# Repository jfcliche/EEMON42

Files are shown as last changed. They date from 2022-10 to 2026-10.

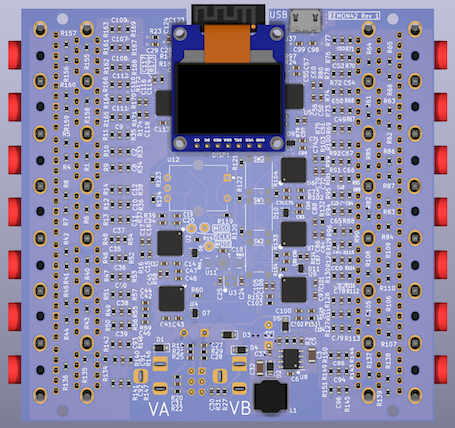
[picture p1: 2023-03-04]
software/sim/eemon42.png

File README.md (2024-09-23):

# EEMON42
ESP32-C3-based 42-channel home energy monitor using the Analog Device ADE7816 emergy monitor chip

Features

  - 42 Current monitoring inputs with 3.5 mm jacks for current transformers
  - Single board, 10x10 cm design with OLED screen with a OLED/switch/rotary encoder user interface
  - Two AC voltage for split phase voltage monitoring and board powering
  - Micropython control software with MQTT telemetry streamed over WiFi

# Status

  V0 Hardware
    - Board is built. 
    - Hardware validation:
      - Switcher works. Board can be powered via USB or AC jacks. 
      - Can operate the ESP32 via the USB and micropython. 
      - All buttons work.
      - OLED display works
      - Only one ADE7816 is populated so far, but we can read registers.
    - Todo: 
      - Check analog inputs of ADE7816. Populate rest of the board. Calibrate all inputs.

  Software
    - Building basic micropyton modules
    - Todo: 
      - Implement main loop and monitoring/GUI tasks as coroutines. Improve display functions. Integrate with Home Assistant.

# Design Details:
- Accurate Energy monitoring performed by seven ADE7816
  - ESP32-C3 controller implemented with a Espressif ESP32-C3-WROOM-02 or AI Thinker ESP-C3-13 module, providing 
      - Single core RISC-V 160 MHz processor
      - 4 MB flash
      - Wifi, Bluetooth
      - Embedded USB controller
  - 96x64 pixel, 0.96" OLED display
  - 3 pushbutton keys 
  - Rotary encoder with integrated push button
  - Dual 9-15VAC inputs for line voltage monitoring and powering the board
  - Micro-USB connector for UART programming and JTAG debugging, and alternate board powering      
  - Integrated DC-DC converter for wide input voltage range

# Rationale

The EEMON42 was developed as personal project for learning all the steps to build an embedded controller project from A to Z, starting from from schematics & layout, online PCB manufacturing, hand soldering of high density SMD devices, an developing the embedded controller software. More specifically, this includes:

   - Learn KiCAD 6.0 and learn to place and route designs
   - Use PCBWay or JLCPCB to manufacture the PCB
   - Learn SMD soldering techniques for sizes down to 0603 and QFN 0.5mm pitch devices
   - Learn the internal architecture of the ESP32-C3-based module
   - Software development tools (Visual Studio Code / Platform IO / ESP IDF/ Micropython etc)

# History

2022/06: Design start
2022/12: Board was manufactured by PCBJLC. Board is assembled. Preliminary hardware verification is performed: power, ESP32, buttons and OLED display works with Micropython. Discovered bug in esptool that prevent the flashing stub to operate when USB-enabled micropython has booted first.
2023/03: ADE7816 is installed. Successful communication with it. Implement Python object for it. Implement SPI object to handle SPI CS pins shared with buttons and pin interrupts.

# Known bugs & gotcha's:

v1 hardware:
  - GPIO9 can be pull down and prevent micropython boot if encoder is left in mid-position
  - Missing GPIO2 & GPIO8 pullup (but still works without those)
  - A reset switch would be nice, but is becoming les and less necessary as hardware matures
  - A power LED would prevent accidental soldering on a powered board...
  - Pad and copper pour cleareaces too small close to USB connector: rookie solderers might cause shorts when applying too much solder...
  - serial number chip (or some GPIO strapping) might be useful for software to identify the hardware automatically. rev2 GPIOs assignments will change.  
  - encoder is a bit too close to screen for big fingers. Buttons should be spread out more.
  - Find socket with proper height for screen.

# Changelog:

 v2 hardware (under development):
  - OLED CS7 is now on FSPICS0 for native hardware-enabled CS toggling (if possible)
  - Encoder Button CS2 is on GPIO9 to prevent unwanted boot mode and allow user-controlled to force downnloader boot (although USB interface does not need it except for esptool bug)
  - CS0 and CS1 moved to other GPIOs
  - Added weak pullups on GPIO2 and GPIO8 to be sure

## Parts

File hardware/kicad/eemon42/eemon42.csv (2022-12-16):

Source: | C:\Users\jfcliche\workspace\EMON36\hardware\kicad\emon36\emon36.kicad_sch
Date: | 2022-12-09 01:26:24
Tool: | Eeschema (6.0.7)
Generator: | C:\Program Files\KiCad\6.0\bin\scripting\plugins/bom_csv_grouped_by_value_with_fp.py
Component Count: | 382
Ref | Qnty | Value | Cmp name | Footprint | Description | Vendor
C1, | 1 | 680uF/35V | C_Polarized_Small_US | Capacitor_THT:CP_Radial_D10.0mm_P5.00mm | Polarized capacitor, small US symbol
C2, C8, C9, C10, C11, C12, C15, C34, C35, C36, C37, C38, C39, C40, C45, C46, C49, C50, C51, C52, C53, C54, C59, C60, C63, C64, C65, C66, C67, C68, C73, C74, C77, C78, C79, C80, C81, C82, C87, C88, C91, C92, C93, C94, C95, C96, C103, C104, C107, C108, C109, C110, C111, C112, C117, C118, | 56 | 22nF | C_Small | Capacitor_SMD:C_0603_1608Metric | Unpolarized capacitor, small symbol
C3, C32, | 2 | 10uF/50V | C_Small | Capacitor_SMD:C_1206_3216Metric | Unpolarized capacitor, small symbol
C4, | 1 | 2.2nF | C_Small | Capacitor_SMD:C_0603_1608Metric | Unpolarized capacitor, small symbol
C5, | 1 | 10nF | C_Small | Capacitor_SMD:C_0603_1608Metric | Unpolarized capacitor, small symbol
C6, C17, C18, C33, C44, C58, C72, C86, C102, C116, | 10 | 0.1uF | C_Small | Capacitor_SMD:C_0603_1608Metric | Unpolarized capacitor, small symbol
C7, | 1 | 220uF/35V | C_Polarized_Small_US | Capacitor_THT:CP_Radial_D10.0mm_P5.00mm | Polarized capacitor, small US symbol
C13, C16, C19, C22, C24, C41, C42, C47, C55, C56, C61, C69, C70, C75, C83, C84, C89, C97, C100, C105, C113, C114, C119, C123, | 24 | 4.7uF/16V | C_Small | Capacitor_SMD:C_0603_1608Metric | Unpolarized capacitor, small symbol
C14, C20, C21, C25, C29, C43, C48, C57, C62, C71, C76, C85, C90, C101, C106, C115, C120, C124, | 18 | 0.22uF | C_Small | Capacitor_SMD:C_0603_1608Metric | Unpolarized capacitor, small symbol
C23, C26, | 2 | 100pF | C_Small | Capacitor_SMD:C_0603_1608Metric | Unpolarized capacitor, small symbol
C27, C28, C30, C31, | 4 | 47nF | C_Small | Capacitor_SMD:C_0603_1608Metric | Unpolarized capacitor, small symbol
C98, C99, | 2 | 22pF | C_Small | Capacitor_SMD:C_0603_1608Metric | Unpolarized capacitor, small symbol
D1, D2, D3, D4, D5, | 5 | B240AE-13 | B240 | Diode_SMD:D_SOD-123F | 40V 2A Schottky Barrier Rectifier Diode, SMB
D6, D7, D8, D9, D10, D11, D12, | 7 | D_Schottky_Dual_CommonAnode_KKA_Parallel | D_Schottky_Dual_CommonAnode_KKA_Parallel | Package_TO_SOT_SMD:SOT-323_SC-70 | Dual Schottky diode, common anode on pin 1
DISP1, | 1 | SSD1331_RGB_OLED_94x64 | SSD1331_RGB_OLED_94x64 | emon36:SSD1331_RGB_OLED_96x64 | Generic connector, double row, 02x10, top/bottom pin numbering scheme (row 1: 1...pins_per_row, row2: pins_per_row+1 ... num_pins), script generated (kicad-library-utils/schlib/autogen/connector/)
H1, H2, H3, H4, H5, H6, H7, H8, H9, H10, H11, H12, H13, H14, H15, H16, H17, H18, H19, H20, H21, H22, H23, H24, H25, H26, H27, H28, H29, H30, H31, H32, | 32 | MountingHole_Pad | MountingHole_Pad | _Connector_Audio_local:STX-4335_Combined_Mounting_Hole | Mounting Hole with connection
J1, J4, | 2 | Barrel_Jack | Barrel_Jack_Switch | emon36:PJ-002A | DC Barrel Jack with an internal switch
J2, J5, J7, J9, J11, J13, J15, | 7 | 6_port_3.5mm_audio_jack_array_module_left_column | 6_port_3.5mm_audio_jack_array_module_left_column | _Connector_Audio_local:6_ports_3.5mm_audio_jack_array_module_left_column | No Description Available
J3, J6, J8, J10, J12, J14, J16, | 7 | 6_port_3.5mm_audio_jack_array_module_right_column | 6_port_3.5mm_audio_jack_array_module_right_column | _Connector_Audio_local:6_ports_3.5mm_audio_jack_array_module_right_column | No Description Available
J17, | 1 | Conn_02x03_Odd_Even | Conn_02x03_Odd_Even | Connector_PinHeader_2.54mm:PinHeader_2x03_P2.54mm_Vertical | Generic connector, double row, 02x03, odd/even pin numbering scheme (row 1 odd numbers, row 2 even numbers), script generated (kicad-library-utils/schlib/autogen/connector/)
J37, | 1 | USB_B_Micro | USB_B_Micro | Connector_USB:USB_Micro-B_Amphenol_10118194_Horizontal | USB Micro Type B connector
L1, | 1 | 82uH | L_Ferrite | Inductor_SMD:L_Bourns_SRN8040TA | Inductor with ferrite core
LOGO1, | 1 | Logo_Open_Hardware_Small | Logo_Open_Hardware_Small | emon36:OSHW_logo_10mm | Open Hardware logo, small
MH1, MH2, MH3, MH4, | 4 | MountingHole | MountingHole | MountingHole:MountingHole_2.7mm_M2.5 | Mounting Hole without connection
R1, R4, R5, R6, R7, R8, R40, R41, R42, R43, R44, R45, R61, R62, R63, R64, R65, R66, R82, R83, R84, R85, R86, R87, R105, R106, R107, R108, R109, R110, R134, R135, R136, R137, R138, R139, R155, R156, R157, R158, R159, R160, | 42 | RB | R_US | Resistor_SMD:R_0603_1608Metric | Resistor, US symbol
R2, | 1 | DNL | R_US | Resistor_SMD:R_0603_1608Metric | Resistor
R3, | 1 | 47k | R_US | Resistor_SMD:R_0603_1608Metric | Resistor
R9, R10, R11, R12, R13, R14, R16, R39, R46, R47, R48, R49, R50, R51, R58, R59, R67, R68, R69, R70, R71, R72, R79, R80, R88, R89, R90, R91, R92, R93, R102, R103, R111, R112, R113, R114, R115, R116, R131, R132, R140, R141, R142, R143, R144, R145, R152, R153, R161, R162, R163, R164, R165, R166, R173, R174, | 56 | 1k | R_US | Resistor_SMD:R_0603_1608Metric | Resistor, US symbol
R15, R17, R18, R60, R81, R104, R133, R154, R175, | 9 | 22 | RES0603 | Resistor_SMD:R_0603_1608Metric | Resistor
R19, R20, R25, R27, | 4 | 21.5K | R_Small_US | Resistor_SMD:R_0603_1608Metric | Resistor, small US symbol
R21, R22, R29, R31, R33, R34, R35, R36, R37, R38, R52, R53, R54, R55, R56, R57, R73, R74, R75, R76, R77, R78, R94, R95, R96, R99, R100, R101, R125, R126, R127, R128, R129, R130, R146, R147, R148, R149, R150, R151, R167, R168, R169, R170, R171, R172, | 46 | 499 | R_US | Resistor_SMD:R_0603_1608Metric | Resistor, US symbol
R23, | 1 | 2.2K | R_US | Resistor_SMD:R_0603_1608Metric | Resistor
R24, R119, R120, R121, R122, R123, R124, | 7 | 2.2k | R_US | Resistor_SMD:R_0603_1608Metric | Resistor
R26, | 1 | DNP | R_US | Resistor_SMD:R_0603_1608Metric | Resistor
R97, R98, | 2 | 0 | R_US | Resistor_SMD:R_0603_1608Metric | Resistor
R117, | 1 | 50 | R_US | Resistor_SMD:R_0603_1608Metric | Resistor
RN1, RN2, | 2 | 33 | R_Network04_US | _SnapEDA Library:RESCAV50P200X100X55-8N | 4 resistor network, star topology, bussed resistors, small US symbol
SW2, SW3, SW4, | 3 | SW_MEC_5E | SW_MEC_5E | _Button_Switch_SMD:SW_Push_1P1T_NO_6x6mm_H13mm | MEC 5E single pole normally-open tactile switch
TP1, | 1 | SCLK | TestPoint | TestPoint:TestPoint_THTPad_D2.0mm_Drill1.0mm | test point
TP2, | 1 | MOSI | TestPoint | TestPoint:TestPoint_THTPad_D2.0mm_Drill1.0mm | test point
TP3, | 1 | MISO | TestPoint | TestPoint:TestPoint_THTPad_D2.0mm_Drill1.0mm | test point
U1, | 1 | ESP32-C3-WROOM-02-N4 | ESP32-C3-WROOM-02-N4 | emon36:MODULE_ESP32-C3-WROOM-02-H4
U2, U4, U5, U6, U7, U9, U10, | 7 | ADE7816 | ADE7816ACPZ | Package_DFN_QFN:QFN-40-1EP_6x6mm_P0.5mm_EP4.6x4.6mm | Single Phase Meter IC 40-LFCSP-WQ _6x6_
U3, | 1 | 16.384MHz | KC2520Z | Oscillator:Oscillator_SMD_Kyocera_KC2520Z-4Pin_2.5x2.0mm | 1.8432MHz ~ 125MHz Crystal Oscillator
U8, | 1 | TPS5403 | TPS54233 | Package_SO:SOIC-8_3.9x4.9mm_P1.27mm | 2A, Step Down DC-DC Converter with Eco-mode, 3.5-28V Input Voltage, SO-8
U11, | 1 | PL133-97QC | PL133-97QC | emon36:PL133-97QC
U12, | 1 | PEC12R-4117F-S0012 | PEC12R-4025F-S0024 | _SnapEDA Library:ENC_PEC12R-4025F-S0024

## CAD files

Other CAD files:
hardware/kicad/eemon42/3d_models/Display/0.96in Color OLED.stp
hardware/kicad/eemon42/3d_models/Bourns_SRN8040TA_series_H3_7mm.step
hardware/kicad/eemon42/3d_models/Display/PmodOLEDrgb.STEP
hardware/kicad/eemon42/3d_models/Display/PmodOLED.STP
hardware/kicad/eemon42/3d_models/EEUFR1V681L.step
hardware/kicad/eemon42/3d_models/PJ-002A.step
hardware/kicad/eemon42/3d_models/PTS645SK13SMTR92LFS.stp
hardware/kicad/eemon42/3d_models/CUI_DEVICES_MJ-3523-SMT-TR.step
hardware/kicad/eemon42/3d_models/ESP32-WROOM-32UE_M113EH2800UH3Q0_.stp
hardware/kicad/eemon42/3d_models/Cap_Murata_GRM188C71C225KE11D_eec.STEP
hardware/kicad/eemon42/3d_models/ESP32-C3-WROOM-02-N4--3DModel-STEP-269445.STEP
hardware/kicad/eemon42/3d_models/ADE7816ACPZ.stp
hardware/kicad/eemon42/3d_models/STX-4335-5BGP-S1_rB3.STEP
hardware/kicad/eemon42/3d_models/10118194-0001LF.step
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

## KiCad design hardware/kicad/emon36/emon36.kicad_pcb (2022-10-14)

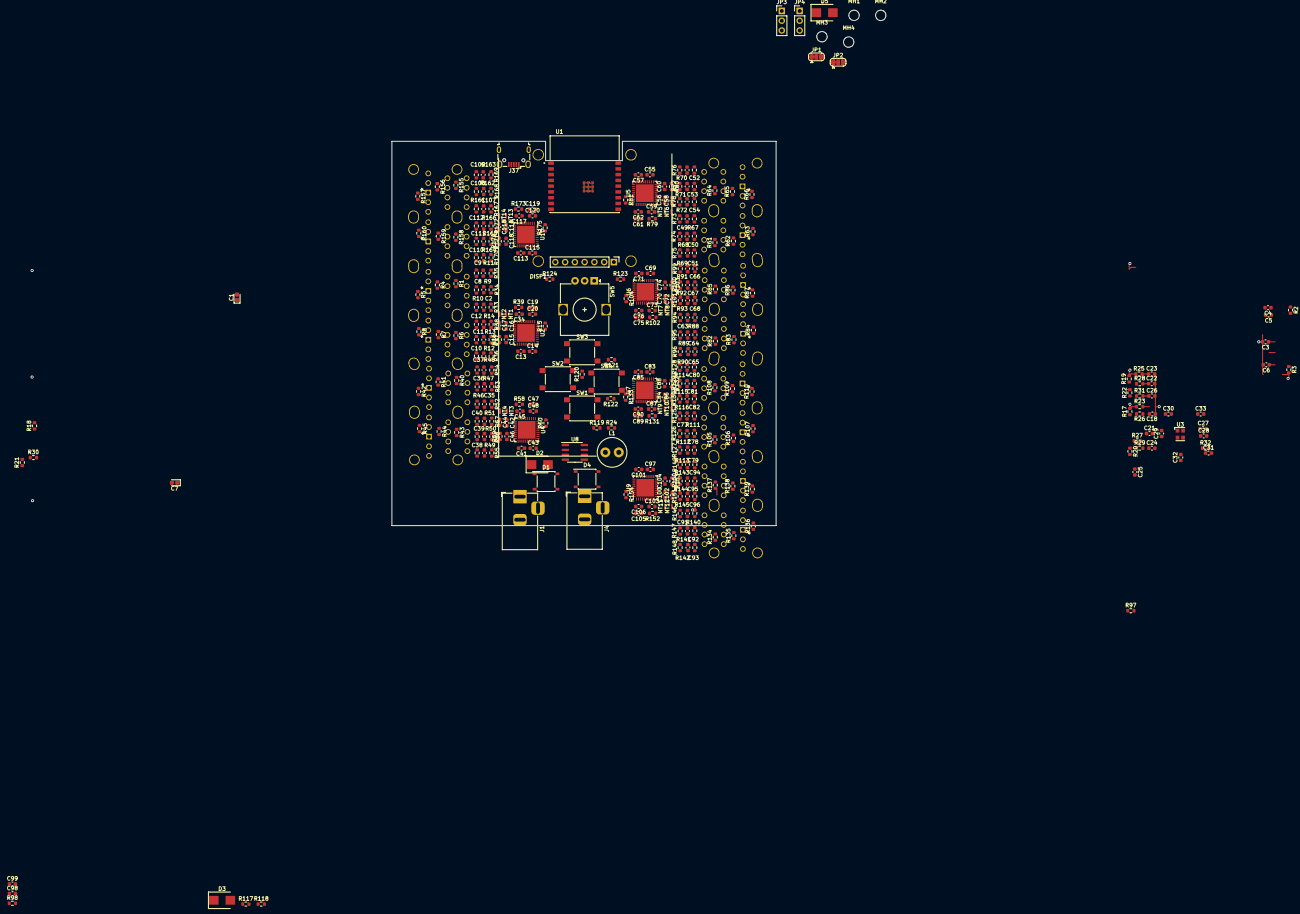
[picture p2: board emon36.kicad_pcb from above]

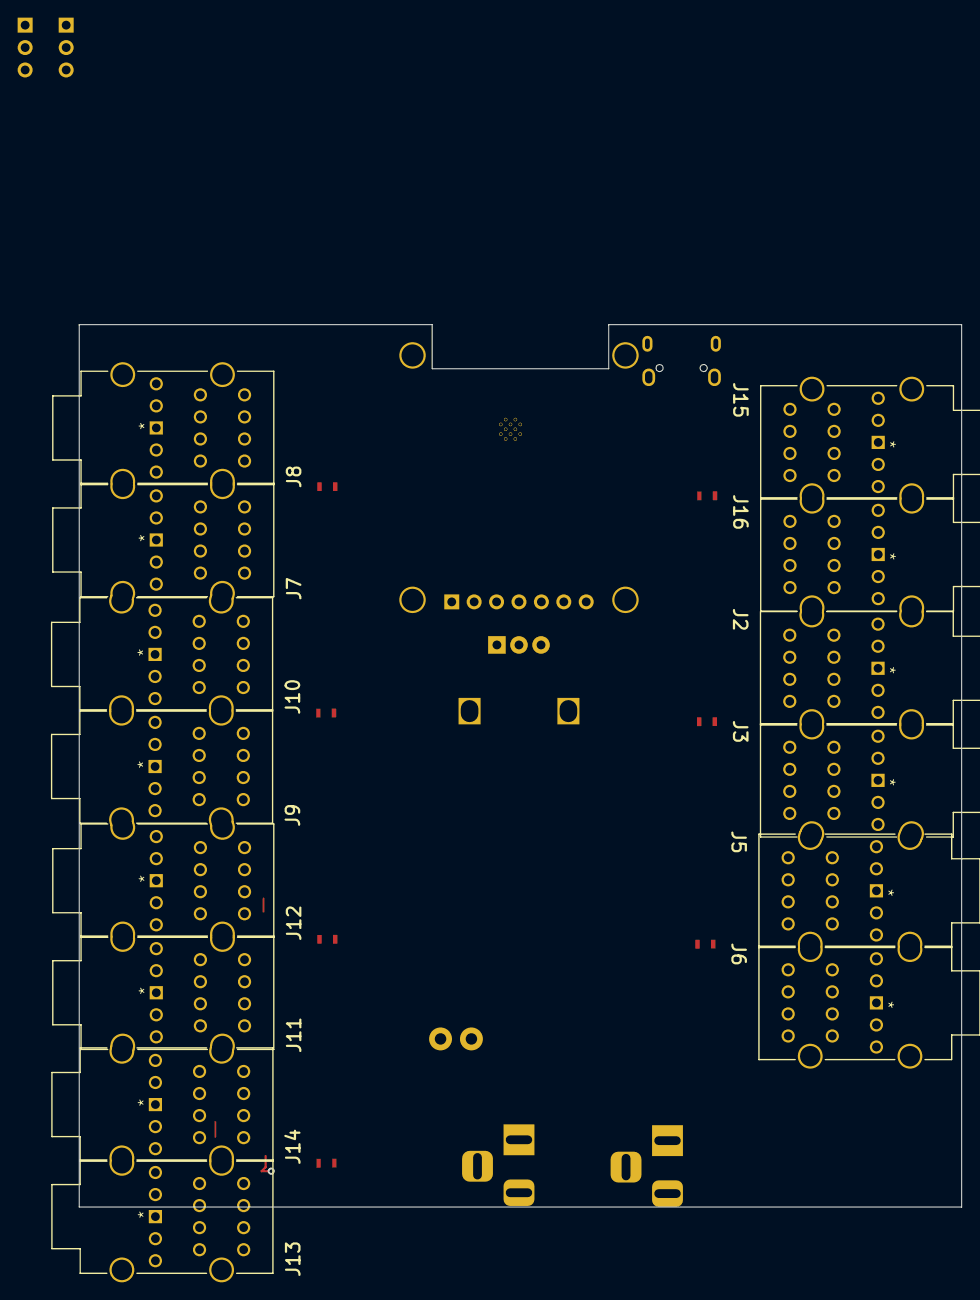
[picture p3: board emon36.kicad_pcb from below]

Board: 4 copper layers, 100.0 x 100.0 mm, 356 parts (14 on the bottom side), 197 nets.

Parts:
C1: 680uF/35V; CP_EIA-1608-08_AVX-J
C2, C8, C9, C10, C11, C12, C15, C34, C35, C36, C37, C38, C39, C40, C45, C46, C49, C50, C51, C52, C53, C54, C59, C60, C63, C64, C65, C66, C67, C68, C73, C74, C77, C78, C79, C80, C81, C82, C87, C88, C91, C92, C93, C94, C95, C96, C103, C104, C107, C108, C109, C110, C111, C112, C117, C118: 22nF; C_0603_1608Metric
C3, C6: 10uF/25V; C_0603_1608Metric
C4: 2.2nF; C_0603_1608Metric
C5, C18, C21, C22, C23, C26, C27, C28, C29: 10nF; C_0603_1608Metric
C7: 220uF/25V; CP_EIA-1608-08_AVX-J
C13, C16, C19, C24, C41, C42, C47, C55, C56, C61, C69, C70, C75, C83, C84, C89, C97, C100, C105, C113, C114, C119: 4.7uF; C_0603_1608Metric
C14, C20, C25, C43, C48, C57, C62, C71, C76, C85, C90, C101, C106, C115, C120: 0.22uF; C_0603_1608Metric
C17, C44, C58, C72, C86, C102, C116: 0.1uF; C_0603_1608Metric
C30, C31, C32, C33: 1uF/35V; C_0603_1608Metric
C98, C99: 22pF; C_0603_1608Metric
D1, D4: ABS6; Diode_Bridge_Diotec_ABS
D2, D3, D5: B240; D_SMB
DISP1: SSD1331_RGB_OLED_94x64; SSD1331_RGB_OLED_96x64
J1, J4: Barrel_Jack; BarrelJack_Horizontal
J2, J3, J5, J6, J7, J8, J9, J10, J11, J12, J13, J14, J15, J16: STX-4335-5BGP-S1; STX-4335-5BGP-S1_KYC
J37: USB_B_Micro; USB_Micro-B_Wuerth_629105150521
JP1, JP2: SolderJumper_3_Bridged12; SolderJumper-3_P1.3mm_Bridged12_RoundedPad1.0x1.5mm
JP3, JP4: Jumper_3_Bridged12; PinHeader_1x03_P2.54mm_Vertical
L1: 82uH; L_Radial_D7.5mm_P3.50mm_Fastron_07P
MH1, MH2, MH3, MH4: MountingHole; MountingHole_2.7mm_M2.5
NT1, NT2, NT3, NT4, NT5, NT6, NT7, NT8, NT9, NT10, NT11, NT12, NT13, NT14: NetTie_2; NetTie-2_SMD_Pad0.5mm
R1, R4, R5, R6, R7, R8, R40, R41, R42, R43, R44, R45, R61, R62, R63, R64, R65, R66, R82, R83, R84, R85, R86, R87, R105, R106, R107, R108, R109, R110, R134, R135, R136, R137, R138, R139, R155, R156, R157, R158, R159, R160: RB; R_0603_1608Metric
R2, R97, R98: 0; R_0603_1608Metric
R3: 47k; R_0603_1608Metric
R9, R10, R11, R12, R13, R14, R16, R39, R46, R47, R48, R49, R50, R51, R58, R59, R67, R68, R69, R70, R71, R72, R79, R80, R88, R89, R90, R91, R92, R93, R102, R103, R111, R112, R113, R114, R115, R116, R131, R132, R140, R141, R142, R143, R144, R145, R152, R153, R161, R162, R163, R164, R165, R166, R173, R174: 1k; R_0603_1608Metric
R15, R60, R81, R104, R133, R154, R175: 22; R_0603_1608Metric
R17, R18, R19, R20, R21, R22, R117, R118: 75; R_0603_1608Metric
R23: 2.2K; R_0603_1608Metric
R24, R119, R120, R121, R122, R123, R124: 2.2k; R_0603_1608Metric
R25, R26, R27, R28: 21.5K; R_0603_1608Metric
R29, R30, R31, R32, R33, R34, R35, R36, R37, R38, R52, R53, R54, R55, R56, R57, R73, R74, R75, R76, R77, R78, R94, R95, R96, R99, R100, R101, R125, R126, R127, R128, R129, R130, R146, R147, R148, R149, R150, R151, R167, R168, R169, R170, R171, R172: 499; R_0603_1608Metric
SW1, SW2, SW3, SW4: SW_MEC_5E; SW_Push_1P1T_NO_6x6mm_H13mm
SW5: RotaryEncoder; RotaryEncoder_Alps_EC12E_Vertical_H20mm
U1: ESP32-C3-WROOM-02-N4; MODULE_ESP32-C3-WROOM-02-H4
U2, U4, U5, U6, U7, U9, U10: QFN-40-1EP_6x6mm_P0.5mm_EP4.6x4.6mm
U3: 16.384MHz; Oscillator_SMD_Kyocera_KC2520Z-4Pin_2.5x2.0mm
U8: TPS54233; SOIC-8_3.9x4.9mm_P1.27mm

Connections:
3V3: C7.1, C24.1, C25.1, D5.2 (A), DISP1.2 (VCC), J37.1 (VBUS), L1.2, R23.1, U1.1 (3V3), U2.2 (PULL_HIGH), U2.26 (VDD), U3.4 (VCC), U4.2 (PULL_HIGH), U4.26 (VDD), U5.2 (PULL_HIGH), U5.26 (VDD), U6.2 (PULL_HIGH), U6.26 (VDD), U7.2 (PULL_HIGH), U7.26 (VDD), U8.5 (FB), U9.2 (PULL_HIGH), U9.26 (VDD), U10.2 (PULL_HIGH), U10.26 (VDD)
/CH0/IABC_N: C107.2, C108.2, C109.2, J15.1, NT13.1, R155.2, R156.2, R157.2, R167.2, R168.2, R169.2
/CH0/IA_P: C107.1, R161.2, R167.1, U10.7 (IAP)
/CH0/IB_P: C108.1, R162.2, R168.1, U10.9 (IBP)
/CH0/IC_P: C109.1, R163.2, R169.1, U10.13 (ICP)
/CH0/IDEF_N: C110.2, C111.2, C112.2, J16.1, NT14.1, R158.2, R159.2, R160.2, R170.2, R171.2, R172.2
/CH0/ID_P: C110.1, R164.2, R170.1, U10.23 (IDP)
/CH0/IE_P: C111.1, R165.2, R171.1, U10.22 (IEP)
/CH0/IF_P: C112.1, R166.2, R172.1, U10.19 (IFP)
/CH1/IABC_N: C2.2, C8.2, C9.2, J2.1, NT1.1, R1.2, R4.2, R5.2, R33.2, R34.2, R35.2
/CH1/IA_P: C2.1, R10.2, R33.1, U2.7 (IAP)
/CH1/IB_P: C8.1, R9.2, R34.1, U2.9 (IBP)
/CH1/IC_P: C9.1, R11.2, R35.1, U2.13 (ICP)
/CH1/IDEF_N: C10.2, C11.2, C12.2, J3.1, NT2.1, R6.2, R7.2, R8.2, R36.2, R37.2, R38.2
/CH1/ID_P: C10.1, R12.2, R36.1, U2.23 (IDP)
/CH1/IE_P: C11.1, R13.2, R37.1, U2.22 (IEP)
/CH1/IF_P: C12.1, R14.2, R38.1, U2.19 (IFP)
/CH2/IABC_N: C35.2, C36.2, C37.2, J5.1, NT3.1, R40.2, R41.2, R42.2, R52.2, R53.2, R54.2
/CH2/IA_P: C35.1, R46.2, R52.1, U4.7 (IAP)
/CH2/IB_P: C36.1, R47.2, R53.1, U4.9 (IBP)
/CH2/IC_P: C37.1, R48.2, R54.1, U4.13 (ICP)
/CH2/IDEF_N: C38.2, C39.2, C40.2, J6.1, NT4.1, R43.2, R44.2, R45.2, R55.2, R56.2, R57.2
/CH2/ID_P: C38.1, R49.2, R55.1, U4.23 (IDP)
/CH2/IE_P: C39.1, R50.2, R56.1, U4.22 (IEP)
/CH2/IF_P: C40.1, R51.2, R57.1, U4.19 (IFP)
/CH3/IABC_N: C49.2, C50.2, C51.2, J7.1, NT5.1, R61.2, R62.2, R63.2, R73.2, R74.2, R75.2
/CH3/IA_P: C49.1, R67.2, R73.1, U5.7 (IAP)
/CH3/IB_P: C50.1, R68.2, R74.1, U5.9 (IBP)
/CH3/IC_P: C51.1, R69.2, R75.1, U5.13 (ICP)
/CH3/IDEF_N: C52.2, C53.2, C54.2, J8.1, NT6.1, R64.2, R65.2, R66.2, R76.2, R77.2, R78.2
/CH3/ID_P: C52.1, R70.2, R76.1, U5.23 (IDP)
/CH3/IE_P: C53.1, R71.2, R77.1, U5.22 (IEP)
/CH3/IF_P: C54.1, R72.2, R78.1, U5.19 (IFP)
/CH4/IABC_N: C63.2, C64.2, C65.2, J9.1, NT7.1, R82.2, R83.2, R84.2, R94.2, R95.2, R96.2
/CH4/IA_P: C63.1, R88.2, R94.1, U6.7 (IAP)
/CH4/IB_P: C64.1, R89.2, R95.1, U6.9 (IBP)
/CH4/IC_P: C65.1, R90.2, R96.1, U6.13 (ICP)
/CH4/IDEF_N: C66.2, C67.2, C68.2, J10.1, NT8.1, R85.2, R86.2, R87.2, R99.2, R100.2, R101.2
/CH4/ID_P: C66.1, R91.2, R99.1, U6.23 (IDP)
/CH4/IE_P: C67.1, R92.2, R100.1, U6.22 (IEP)
/CH4/IF_P: C68.1, R93.2, R101.1, U6.19 (IFP)
/CH5/IABC_N: C77.2, C78.2, C79.2, J11.1, NT9.1, R105.2, R106.2, R107.2, R125.2, R126.2, R127.2
/CH5/IA_P: C77.1, R111.2, R125.1, U7.7 (IAP)
/CH5/IB_P: C78.1, R112.2, R126.1, U7.9 (IBP)
/CH5/IC_P: C79.1, R113.2, R127.1, U7.13 (ICP)
/CH5/IDEF_N: C80.2, C81.2, C82.2, J12.1, NT10.1, R108.2, R109.2, R110.2, R128.2, R129.2, R130.2
/CH5/ID_P: C80.1, R114.2, R128.1, U7.23 (IDP)
/CH5/IE_P: C81.1, R115.2, R129.1, U7.22 (IEP)
/CH5/IF_P: C82.1, R116.2, R130.1, U7.19 (IFP)
/CH6/IABC_N: C91.2, C92.2, C93.2, J13.1, NT11.1, R134.2, R135.2, R136.2, R146.2, R147.2, R148.2
/CH6/IA_P: C91.1, R140.2, R146.1, U9.7 (IAP)
/CH6/IB_P: C92.1, R141.2, R147.1, U9.9 (IBP)
/CH6/IC_P: C93.1, R142.2, R148.1, U9.13 (ICP)
/CH6/IDEF_N: C94.2, C95.2, C96.2, J14.1, NT12.1, R137.2, R138.2, R139.2, R149.2, R150.2, R151.2
/CH6/ID_P: C94.1, R143.2, R149.1, U9.23 (IDP)
/CH6/IE_P: C95.1, R144.2, R150.1, U9.22 (IEP)
/CH6/IF_P: C96.1, R145.2, R151.1, U9.19 (IFP)
/CLK16MHZ: R17.1, R18.1, R19.1, R20.1, R21.2, U2.27 (CLKIN), U4.27 (CLKIN), U5.27 (CLKIN), U6.27 (CLKIN), U7.27 (CLKIN), U9.27 (CLKIN), U10.27 (CLKIN)
/IRQ: R24.2, U2.29 (*IRQ0), U2.32 (*IRQ1), U4.29 (*IRQ0), U4.32 (*IRQ1), U5.29 (*IRQ0), U5.32 (*IRQ1), U6.29 (*IRQ0), U6.32 (*IRQ1), U7.29 (*IRQ0), U7.32 (*IRQ1), U9.29 (*IRQ0), U9.32 (*IRQ1), U10.29 (*IRQ0), U10.32 (*IRQ1)
/OLED_C/~D: DISP1.6 (D/~C), U1.17 (GPIO1_ADC1CH1_XTAL32N)
/OLED_RES: DISP1.5 (~RES), U1.18 (GPIO0_ADC1CH0_XTAL32P)
/RESET: C29.1, R23.2, U1.2 (EN), U2.4 (~RESET), U4.4 (~RESET), U5.4 (~RESET), U7.4 (~RESET), U9.4 (~RESET), U10.4 (~RESET)
/SPI_CS0: R123.1, U1.10 (GPIO10_FSPICS0), U10.39 (*SS/HAS)
/SPI_CS1: R124.1, U1.8 (GPIO9), U2.39 (*SS/HAS)
/SPI_CS2: R119.1, U1.7 (GPIO8), U4.39 (*SS/HAS)
/SPI_CS3: R120.1, U1.15 (GPIO3_ADC1CH3), U5.39 (*SS/HAS)
/SPI_CS4: R121.1, U1.4 (GPIO5_ADC2CH0_FSPIWP_MTDI), U6.39 (*SS/HAS)
/SPI_CS5: R122.1, U1.3 (GPIO4_ADC1_CH4_FSPIHD_MTMS), U7.39 (*SS/HAS)
/SPI_CS6: R24.1, U1.12 (GPIO21_UART0TXD), U9.39 (*SS/HAS)
/SPI_CS7: DISP1.7 (~CS), U1.11 (GPIO20_UART0RXD)
/SPI_MISO: R15.2, R22.1, R60.2, R81.2, R104.2, R133.2, R154.2, R175.2, U1.16 (GPIO2_ADC1CH2_FSPIQ)
/SPI_MOSI: DISP1.4 (SDA), R118.1, U1.6 (GPIO7_FSPID_MTDO), U2.38 (MOSI/SDA), U4.38 (MOSI/SDA), U5.38 (MOSI/SDA), U6.38 (MOSI/SDA), U7.38 (MOSI/SDA), U9.38 (MOSI/SDA), U10.38 (MOSI/SDA)
/SPI_SCLK: DISP1.3 (SCL), R117.1, U1.5 (GPIO6_FSPICLK_MTCK), U2.36 (SCLK/SCL), U4.36 (SCLK/SCL), U5.36 (SCLK/SCL), U6.36 (SCLK/SCL), U7.36 (SCLK/SCL), U9.36 (SCLK/SCL), U10.36 (SCLK/SCL)
/USB_D+: C99.1, J37.3 (D+), R98.1
/USB_D-: C98.1, J37.2 (D-), R97.1
/VA+: JP3.1 (A), R25.2, R29.1, U2.15 (VP), U4.15 (VP), U5.15 (VP), U10.15 (VP)
/VA-: JP4.1 (A), R26.2, R30.2, U2.16 (VN), U4.16 (VN), U5.16 (VN), U10.16 (VN)
/VB+: JP3.2 (C), U6.15 (VP), U7.15 (VP), U9.15 (VP)
/VB-: JP4.2 (C), U6.16 (VN), U7.16 (VN), U9.16 (VN)
/VBI+: JP3.3 (B), R27.2, R31.1
/VBI-: JP4.3 (B), R28.2, R32.2
GND: C1.2, C3.2, C4.2, C5.2, C7.2, C13.2, C14.2, C15.2, C16.2, C17.2, C18.2, C19.2, C20.2, C21.2, C22.2, C23.2, C24.2, C25.2, C26.2, C27.2, C28.2, C29.2, C34.2, C41.2, C42.2, C43.2, C44.2, C45.2, C46.2, C47.2, C48.2, C55.2, C56.2, C57.2, C58.2, C59.2, C60.2, C61.2, C62.2, C69.2, C70.2, C71.2, C72.2, C73.2, C74.2, C75.2, C76.2, C83.2, C84.2, C85.2, C86.2, C87.2, C88.2, C89.2, C90.2, C97.2, C98.2, C99.2, C100.2, C101.2, C102.2, C103.2, C104.2, C105.2, C106.2, C113.2, C114.2, C115.2, C116.2, C117.2, C118.2, C119.2, C120.2, D2.2 (A), DISP1.1 (GND), J37.5 (GND), JP1.2 (C), JP2.2 (C), NT1.2, NT2.2, NT3.2, NT4.2, NT5.2, NT6.2, NT7.2, NT8.2, NT9.2, NT10.2, NT11.2, NT12.2, NT13.2, NT14.2, R2.2, R16.1, R29.2, R30.1, R31.2, R32.1, R39.1, R58.1, R59.1, R79.1, R80.1, R102.1, R103.1, R131.1, R132.1, R152.1, R153.1, R173.1, R174.1, SW5.C, U1.9 (GND), U1.19 (GND), U1.20 (GND), U1.21 (GND), U1.22 (GND), U1.23 (GND), U1.24 (GND), U1.25 (GND), U1.26 (GND), U1.27 (GND), U2.1 (NC_4), U2.3 (PULL_LOW), U2.6 (DGND), U2.10 (NC_6), U2.11 (NC_8), U2.20 (NC_10), U2.21 (NC_2), U2.25 (AGND), U2.30 (NC_3), U2.31 (NC_5), U2.40 (NC), U2.41 (EP(AGND)), U3.2 (GND), U4.1 (NC_4), U4.3 (PULL_LOW), U4.6 (DGND), U4.10 (NC_6), U4.11 (NC_8), U4.20 (NC_10), U4.21 (NC_2), U4.25 (AGND), U4.30 (NC_3), U4.31 (NC_5), U4.40 (NC), U4.41 (EP(AGND)), U5.1 (NC_4), U5.3 (PULL_LOW), U5.6 (DGND), U5.10 (NC_6), U5.11 (NC_8), U5.20 (NC_10), U5.21 (NC_2), U5.25 (AGND), U5.30 (NC_3), U5.31 (NC_5), U5.40 (NC), U5.41 (EP(AGND)), U6.1 (NC_4), U6.3 (PULL_LOW), U6.6 (DGND), U6.10 (NC_6), U6.11 (NC_8), U6.20 (NC_10), U6.21 (NC_2), U6.25 (AGND), U6.30 (NC_3), U6.31 (NC_5), U6.40 (NC), U6.41 (EP(AGND)), U7.1 (NC_4), U7.3 (PULL_LOW), U7.6 (DGND), U7.10 (NC_6), U7.11 (NC_8), U7.20 (NC_10), U7.21 (NC_2), U7.25 (AGND), U7.30 (NC_3), U7.31 (NC_5), U7.40 (NC), U7.41 (EP(AGND)), U8.7 (GND), U9.1 (NC_4), U9.3 (PULL_LOW), U9.6 (DGND), U9.10 (NC_6), U9.11 (NC_8), U9.20 (NC_10), U9.21 (NC_2), U9.25 (AGND), U9.30 (NC_3), U9.31 (NC_5), U9.40 (NC), U9.41 (EP(AGND)), U10.1 (NC_4), U10.3 (PULL_LOW), U10.6 (DGND), U10.10 (NC_6), U10.11 (NC_8), U10.20 (NC_10), U10.21 (NC_2), U10.25 (AGND), U10.30 (NC_3), U10.31 (NC_5), U10.40 (NC), U10.41 (EP(AGND))
unnamed: C1.1, D1.1 (+), D3.2 (A), D4.1 (+)
unnamed: C3.1, D3.1 (K), D5.1 (K), U8.2 (VIN)
unnamed: C4.1, R3.2
unnamed: C5.1, U8.4 (SS)
unnamed: C6.1, U8.1 (BOOT)
unnamed: C6.2, D2.1 (K), L1.1, U8.8 (PH)
unnamed: C18.1, C21.1, C22.1, C23.1, R17.2, R18.2, R19.2, R20.2
unnamed: C28.1, R22.2
unnamed: C30.1, R25.1
unnamed: C30.2, D1.4, J1.1
unnamed: C31.1, D1.3, J1.2, JP1.3 (B)
unnamed: C31.2, R26.1
unnamed: C32.1, R27.1
unnamed: C32.2, D4.4, J4.1
unnamed: C33.1, D4.3, J4.2, JP2.3 (B)
unnamed: C33.2, R28.1
unnamed: C41.1, C43.1, U4.24 (AVDD)
unnamed: C42.1, C44.1, U4.17 (REFIN/OUT)
unnamed: C45.1, R58.2, U4.8 (IAN), U4.12 (IBN), U4.14 (ICN)
unnamed: C46.1, R59.2, U4.18 (IN)
unnamed: C47.1, C48.1, U4.5 (DVDD)
unnamed: C55.1, C57.1, U5.24 (AVDD)
unnamed: C56.1, C58.1, U5.17 (REFIN/OUT)
unnamed: C59.1, R79.2, U5.8 (IAN), U5.12 (IBN), U5.14 (ICN)
unnamed: C60.1, R80.2, U5.18 (IN)
unnamed: C61.1, C62.1, U5.5 (DVDD)
unnamed: C69.1, C71.1, U6.24 (AVDD)
unnamed: C70.1, C72.1, U6.17 (REFIN/OUT)
unnamed: C73.1, R102.2, U6.8 (IAN), U6.12 (IBN), U6.14 (ICN)
unnamed: C74.1, R103.2, U6.18 (IN)
unnamed: C75.1, C76.1, U6.5 (DVDD)
unnamed: C83.1, C85.1, U7.24 (AVDD)
unnamed: C84.1, C86.1, U7.17 (REFIN/OUT)
unnamed: C87.1, R131.2, U7.8 (IAN), U7.12 (IBN), U7.14 (ICN)
unnamed: C88.1, R132.2, U7.18 (IN)
unnamed: C89.1, C90.1, U7.5 (DVDD)
unnamed: C100.1, C102.1, U9.17 (REFIN/OUT)
unnamed: C97.1, C101.1, U9.24 (AVDD)
unnamed: C103.1, R152.2, U9.8 (IAN), U9.12 (IBN), U9.14 (ICN)
unnamed: C104.1, R153.2, U9.18 (IN)
unnamed: C105.1, C106.1, U9.5 (DVDD)
unnamed: C113.1, C115.1, U10.24 (AVDD)
unnamed: C114.1, C116.1, U10.17 (REFIN/OUT)
unnamed: C117.1, R173.2, U10.8 (IAN), U10.12 (IBN), U10.14 (ICN)
unnamed: C118.1, R174.2, U10.18 (IN)
unnamed: C119.1, C120.1, U10.5 (DVDD)
unnamed: D1.2 (-), JP1.1 (A)
unnamed: D4.2 (-), JP2.1 (A)
unnamed: J2.5, R5.1, R11.1
unnamed: J2.25, R4.1, R9.1
unnamed: J2.35, R1.1, R10.1
unnamed: J3.5, R8.1, R14.1
unnamed: J3.25, R7.1, R13.1
unnamed: J3.35, R6.1, R12.1
unnamed: J5.5, R42.1, R48.1
unnamed: J5.25, R41.1, R47.1
unnamed: J5.35, R40.1, R46.1
unnamed: J6.5, R45.1, R51.1
unnamed: J6.25, R44.1, R50.1
unnamed: J6.35, R43.1, R49.1
unnamed: J7.5, R63.1, R69.1
unnamed: J7.25, R62.1, R68.1
unnamed: J7.35, R61.1, R67.1
unnamed: J8.5, R66.1, R72.1
unnamed: J8.25, R65.1, R71.1
unnamed: J8.35, R64.1, R70.1
unnamed: J9.5, R84.1, R90.1
unnamed: J9.25, R83.1, R89.1
unnamed: J9.35, R82.1, R88.1
unnamed: J10.5, R87.1, R93.1
unnamed: J10.25, R86.1, R92.1
unnamed: J10.35, R85.1, R91.1
unnamed: J11.5, R107.1, R113.1
unnamed: J11.25, R106.1, R112.1
unnamed: J11.35, R105.1, R111.1
unnamed: J12.5, R110.1, R116.1
unnamed: J12.25, R109.1, R115.1
unnamed: J12.35, R108.1, R114.1
unnamed: J13.5, R136.1, R142.1
unnamed: J13.25, R135.1, R141.1
unnamed: J13.35, R134.1, R140.1
unnamed: J14.5, R139.1, R145.1
unnamed: J14.25, R138.1, R144.1
unnamed: J14.35, R137.1, R143.1
unnamed: J15.5, R157.1, R163.1
unnamed: J15.25, R156.1, R162.1
unnamed: J15.35, R155.1, R161.1
unnamed: J16.5, R160.1, R166.1
unnamed: J16.25, R159.1, R165.1
unnamed: J16.35, R158.1, R164.1
unnamed: R2.1, U8.3 (EN)
unnamed: R3.1, U8.6 (COMP)
unnamed: R15.1, U2.37 (MISO/HSD)
unnamed: C15.1, R16.2, U2.18 (IN)
unnamed: R21.1, U3.3 (CLK)
unnamed: R60.1, U4.37 (MISO/HSD)
unnamed: R81.1, U5.37 (MISO/HSD)
unnamed: R97.2, U1.13 (GPIO18_USB-)
unnamed: R98.2, U1.14 (GPIO19_USB+)
unnamed: R104.1, U6.37 (MISO/HSD)
unnamed: C26.1, R117.2
unnamed: C27.1, R118.2
unnamed: R119.2, SW1.1, SW1.2
unnamed: R120.2, SW2.1, SW2.2
unnamed: R121.2, SW3.1, SW3.2
unnamed: R122.2, SW4.1, SW4.2
unnamed: R123.2, SW5.A
unnamed: R124.2, SW5.B
unnamed: R133.1, U7.37 (MISO/HSD)
unnamed: R154.1, U9.37 (MISO/HSD)
unnamed: R175.1, U10.37 (MISO/HSD)
unnamed: C19.1, C20.1, U2.5 (DVDD)
unnamed: C34.1, R39.2, U2.8 (IAN), U2.12 (IBN), U2.14 (ICN)
unnamed: C16.1, C17.1, U2.17 (REFIN/OUT)
unnamed: C13.1, C14.1, U2.24 (AVDD)

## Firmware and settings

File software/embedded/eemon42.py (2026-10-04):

import network
import time

def heap_info():
    import gc
    gc.collect()
    print("Python heap free:", gc.mem_free())
    try:
        import esp32
        print("IDF heap:", esp32.idf_heap_info(esp32.HEAP_DATA))
    except ImportError:
        pass
print('heap_info() defined')
heap_info()


# Initialize WiFi client
network.country("CA")  # ← required on ESP32-C3, prevents channel/region errors

nic = network.WLAN(network.STA_IF)
nic.active(False)       # ← force clean state (fixes 0x0102 on many C3 boards)
nic.active(True)
time.sleep(0.8)         # ← let the driver finish initializing
# nic.config(txpower=14)  # ← lower TX power (fixes RF issues on C3)nic.active(True)
nic.config(txpower=5)
nic.config(pm=nic.PM_NONE)
nic.connect('igloot', 'fifafoiot')
while not nic.isconnected():
    time.sleep(0.1)
print(nic.ifconfig())
# nic.disconnect()
# network_connected.clear()


import os
import sys

is_micropython = sys.implementation.name == 'micropython'

# from ssd1331 import SSD1331 as Display  # 96x64 OLED display
from st7735 import ST7735 as Display  # 128x160 LCD display

# Allocate large frame buffer as early as possible before memory is too fragmented
fb = memoryview(bytearray(Display.WIDTH * Display.HEIGHT * Display.BYTES_PER_PIXEL)) # frame buffer, 2 bytes per pixel

# standard packages
from machine import Pin
import time
import machine
import network
import json


import asyncio
import gc


try:
    from asyncio import ThreadSafeFlag
except ImportError:
    from asyncio import Event as ThreadSafeFlag

from ade7816 import ADE7816  # Energy monitor chip
from button import Button  # Pushbutton
from rotary_encoder import RotaryEncoder


# local packages
from spi import SPI_with_CS
from gui import GUI
from namespace import Namespace
from hass import HomeAssistant
import menus



class EEMON42:
    """ EEMON42 main application.
    """

    # topic_sub = b'notification'
    # topic_pub = b'home/sensor1/infojson'

    CONFIG_FOLDER = '/config'
    # SECRETS_FOLDER = os.path.dirname(os.path.abspath(__file__))  # os.path not supported in micropython
    SECRETS_FOLDER = '.'

    def __init__(self):
        """ Create EEMON42 hardware objects
        """
        gc.collect()

        self.config = None
        self.secrets = None
        self.spi = None
        self.display = None
        self.gui = None
        self.client = None # wifi client
        self.fatal_error = False
        self.client_id = machine.unique_id().hex()
        self.nic = None
        self.network_connected = asyncio.Event()

        self.message_interval = 5
        self.screen_saver_timeout = 120

        print('Welcome to EEMON42')
        print('   Creating EEMON42 instance')

        heap_info()

        print('   Loading configuration file')
        self.config = self.load_config(self.CONFIG_FOLDER + '/config.json')
        self.secrets = self.load_config(self.SECRETS_FOLDER + '/secrets.json')

        print('   Connecting wifi')

        heap_info()

        # # Initialize WiFi client
        # self.nic = network.WLAN(network.STA_IF)
        # self.nic.active(True)
        # self.nic.disconnect()
        # self.network_connected.clear()

        self.nic = nic

        self.hass = HomeAssistant(
            self.config, self.secrets, network_ready=self.network_connected
        )

        self.irq_flag = ThreadSafeFlag()
        # Pin definitions
        # Pin numbers are GPIO numbers, not package pins numbers
        self.pin_sck = Pin(6, Pin.OUT)  # SPI clock
        self.pin_mosi = Pin(7, Pin.OUT) # SPI MOSI
        self.pin_miso = Pin(2, Pin.IN)  # SPI MISO
        self.pin_cs7_disp = Pin(20, Pin.OUT) # SPI display chip select (not shared)
        self.pin_cd = Pin(1, Pin.OUT) # SPI Display Command/Data line
        self.pin_res = Pin(0, Pin.OUT) # SPI display reset
        # The following pins are dual functions (EMON chip-select and switches or IRQ).
        # Their mode is managed by the SPI module
        self.pin_cs0_rota = Pin(10)
        self.pin_cs1_rotb = Pin(9)
        self.pin_cs2_button_rot = Pin(8) # Rotary encoder pushbutton switch
        self.pin_cs3_button_a = Pin(3) # SW2, bottom switch, usually ENTER
        self.pin_cs4_button_b = Pin(5) # SW3, top switch, usually ESC/BACK
        self.pin_cs5_button_c = Pin(4) # SW4, middle switch, usually SHIFT
        self.pin_cs6_irq = Pin(21)

        # List of pins that are used as ADE7816 chip select outputs. 
        # Those are *ALSO* used for buttton/encoder/irq inputs
        emon_cs_pins = (self.pin_cs0_rota, 
                        self.pin_cs1_rotb,
                        self.pin_cs2_button_rot,
                        self.pin_cs3_button_a,
                        self.pin_cs4_button_b,
                        self.pin_cs5_button_c,
                        self.pin_cs6_irq)

        # Instantiate the SPI controller
        self.spi = SPI_with_CS(
                baudrate=2500000,  # 2.5 MHz clock 
                sck=self.pin_sck,
                mosi=self.pin_mosi,
                miso=self.pin_miso,
                cs_inout_pins=emon_cs_pins  # these pins are set to mode=Pin.OUT during SPI transactions to prevent button operations to enable CS lines 
                )

        # gc.collect()

        # Display handler
        self.display = Display(spi=self.spi, cs_pin=self.pin_cs7_disp, cd_pin=self.pin_cd, res_pin=self.pin_res, fb=fb)

        self.counter = 0

        # Button handlers
        self.button_rot = Button(self.pin_cs2_button_rot, irq_wrapper=self.spi.get_irq)
        self.button_a = Button(self.pin_cs3_button_a, irq_wrapper=self.spi.get_irq)
        self.button_b = Button(self.pin_cs4_button_b, irq_wrapper=self.spi.get_irq)
        self.button_c = Button(self.pin_cs5_button_c, irq_wrapper=self.spi.get_irq)

        # Rotary Encoder handler
        self.rot_enc = RotaryEncoder(
            pin_a=self.pin_cs0_rota, 
            pin_b=self.pin_cs1_rotb,
            button_shift = self.button_c, 
            irq_wrapper=self.spi.get_irq, # provide a IRQ handler that is disabled during SPI transactions
            verbose=0)

        # Create the 7 energy monitor chip handlers
        eemon_conf = self.config.setdefault('emon',[Namespace()]*len(emon_cs_pins)) # Create eemon entry if it does not exists
        self.emon = [ADE7816(
                        spi=self.spi, cs_pin=cs_pin, irq_pin=self.pin_cs6_irq, 
                        irq_wrapper=self.spi.get_irq, 
                        index=ix, 
                        config=eemon_conf[ix]) 
                     for ix, cs_pin in enumerate(emon_cs_pins)]

        # Setup the ADE7816 IRQ line interrupt handler
        self.pin_cs6_irq.irq(handler=self.spi.get_irq(self.emon_irq_handler));
         

        # Create the GUI (display + buttons, menu system etc) handler
        self.gui = GUI(
            self.display, 
            self.rot_enc, 
            self.button_rot, button_enter=self.button_a, button_esc=self.button_b, button_shift=self.button_c)

        print('   Instantiation complete')

    def emon_irq_handler(self, pin):
        """ IRQ handler to process changes on the EMON IRQ line 

        This being called as an IRQ service call in micropython, only thread safe actions must be performed. 
        """
        if not pin.value(): # only set the event if the IRQ line went low
            self.irq_flag.set()

    def init(self):
        """ Initialize hardware

        This function toggles bits and communicates with the external hardware to bring it into known conditions, as opposed to ``__init__``
        which only created the hardware objects.
        """
        # Initialize display
        self.display.init()
        # self.display.print("EEMON42\r\nis\r\nthe\r\nbest\nof\nall", fg=self.display.YELLOW, font_size=5)

        # Initialize Energy Monitor ICs

        for e in self.emon:
            e.init()
        # time.sleep(1)
        # self.display.clear()

        self.gui.init()

    async def wifi_connection(self):
        """Connect to WiFi and signal ``network_connected`` for other tasks."""
        print('Starting WiFi connection Task')


        # self.nic = network.WLAN(network.STA_IF)
        # self.nic.active(True)
        # self.nic.disconnect()
        # self.network_connected.clear()
        # nic = self.nic
        try:
            while True:
                if not self.nic.isconnected():
                    if self.network_connected.is_set():
                        print('WiFi disconnected')
                    self.network_connected.clear()
                    # self.nic = None
                    ssid = self.secrets['ssid']
                    password = self.secrets['password']
                    print(f"Waiting for WiFi connection to {ssid}")
                    self.nic.active(False)
                    self.nic.active(True)
                 
                    self.nic.connect(ssid, password)
                    while not self.nic.isconnected():
                        await asyncio.sleep(0.3)
                    print('WiFi connection successful')
                    print(self.nic.ifconfig())
                    self.network_connected.set()
                    print('WiFi connection completed')
                await asyncio.sleep(1)
        except BaseException as e:
            print(f'Exception on Wifi task: {e!r}')
            raise
        finally:
            print('Wifi connection task has terminated')
            self.network_connected.clear()
            self.nic = None
            nic.disconnect()


    def load_config(self, filename):
        # If running on-board, always load the config from the '/config' folder, even if the current 
        # working directory is elsewhere (e.g. folder ``/remote`` if we run through ``mpremote mount``)
        # If running on a PC, use ``software/embedded`` (see sim ``CONFIG_FOLDER``).
        try:
            with open(filename) as json_file:
                config = Namespace(json.load(json_file))
        except OSError:
            print(f'Configuration file "{filename} not found. Loading empty config')
            config = Namespace()  # Create empty config
        return config    

 
    def dispose(self):
        self.display.clear()
        self.spi.deinit()
        self.spi = None

    async def screen_saver(self, timeout=120):
        print('Starting screen saver task')
        try:
            while True:
                dt = int(time.time() - self.display.last_time) 
                if dt > 2*timeout:
                    self.display.set_brightness(0) # turn off display
                elif dt > timeout:
                    self.display.set_brightness(1) # set minimum brightness
                await asyncio.sleep(1)
        except BaseException as e:
            print(f'Exception in screen_saver: {e!r}')
            raise
        finally:
            print('Screen saver task has terminated')
    async def watchdog(self): 
        """ Monitors the system status flags and reset the board if a fatal error is detected
        """
        while True:
            if self.fatal_error:
                self.restart_and_reconnect()
            await asyncio.sleep(1)

    async def scan_emon(self):
        print('Starting EMON scanning task')
        dev = 0  # current energy monitor device number
        n_dev = len(self.emon) # total number of energy monitor devices

        # define local variables for faster access
        emon = self.emon
        irq_pin = self.pin_cs6_irq  
        irq_flag = self.irq_flag
        spi = self.spi
        print(f'IRQ={self.pin_cs6_irq()}')

        try:
            while True:
                # If there is not already an IRQ, wait for the IRQ flag to be set by the pin interrupt, 
                # but continue anyways after a timeout in case the IRQ pin went low without the interrupt being processed
                if irq_pin(): # if no interrupt is pending
                    # print(f'IRQ={irq_pin()}')
                    try:
                        await asyncio.wait_for(irq_flag.wait(), 13)
                        irq_flag.clear()
                    except asyncio.TimeoutError:
                        print(f'Timout while waiting for IRQ, {dev=}, IRQ={irq_pin()}')

                scanned_dev = 0
                while not irq_pin() and not spi.spi_active and scanned_dev < n_dev:
                    emon[dev].irq_handler(irq_pin)
                    dev += 1
                    if dev >= n_dev: 
                        dev = 0
                    scanned_dev += 1
                    # print(f'{dev=} {scanned_dev=}')
                    await asyncio.sleep(0.01)  # be a good neighbor and give back control to the event loop to let the UI respond to user actions 
                # print('---')
                # await asyncio.sleep(0.1)
        except BaseException as e:
            print(f'Exception in EMON scanning: {e!r}')
            raise
        finally:
            print('EMON scanning task has terminated')

    async def publish_task(self):
        """Publish dummy sensor readings to Home Assistant (placeholder for EMON telemetry)."""
        entity_id = 'sensor.eemon42_dummy'
        value = 0
        print('Starting Home Assistant publish task')
        try:
            while True:
                await self.network_connected.wait()
                value += 1
                try:
                    await self.hass.set_state(
                        entity_id,
                        value,
                        {'unit_of_measurement': 'W', 'friendly_name': 'EEMON42 dummy'},
                    )
                except OSError as e:
                    print(f'Home Assistant publish failed: {e!r}')
                await asyncio.sleep(3)
        except asyncio.CancelledError:
            raise
        finally:
            print('Home Assistant publish task has terminated')

    async def main_loop(self, extra_tasks = tuple()):

        self.init()

        print('Starting main loop')

        # Start background tasks
        # print('Starting background tasks')
        task_list = (
            self.screen_saver(timeout=self.screen_saver_timeout), # turn off the display after `timeout`
            self.scan_emon(),
            # self.watchdog(), # reboots if there is a fatal error
            self.wifi_connection(), # connect wifi
            self.hass.run(),
            self.publish_task(),
            # self.mqtt_connect_and_subscribe(), # connects MQTT client when wifi is up
            # self.process_mqtt_messages() # sends MQTT messages when MQTT client is connected
            menus.run_main_menu(self.gui, app=self),
            );
        tasks = tuple(asyncio.create_task(t) for t in task_list) + extra_tasks
        try:
            print('Starting all background tasks')
            results = await asyncio.gather(*tasks, return_exceptions=False)  # return_exceptions=False: will raise an exception as soon as one of the tasks raise one (other tasks won't be cancelled)
        except (KeyboardInterrupt, asyncio.CancelledError):
            print(f'Main loop interrupted by user')
 
        # make sure we cancel all background tasks when exiting
        for t in tasks:
            t.cancel()
        # Wait until all task are completed 
        # return_exceptions=True: Will return only when all tasks are done, with or without exceptions. The ones that had not already failed should stop due to the cancellation. 
        await asyncio.gather(*tasks, return_exceptions=True) 
        print('Disposing EEMON42 resources...')
        self.dispose()
        print('Exiting main loop')
 
    def run(self):
        try:
            asyncio.run(self.main_loop())  # Can't use the parameter debug in micropython
        except (KeyboardInterrupt):
            print('Interrupted')
        except:
            raise
# if __name__ == '__main__':
#     e = EEMON42()
#     d = e.display
#     e.run()

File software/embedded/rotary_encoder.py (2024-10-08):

import time

class RotaryEncoder():
    """ Creates a rotary encoder decoding object connected to `pin_a` and `pin_b` and sets the interrupt on these pins
    to continuously keep track of the encoder movements.

    The rotary encoder sequence for the two encoder pins is 11, 01, 00, 10, 11 for clockwise rotation, 
    and the sequence is in the opposite direction for counterclockwise rotation.
    The detent (stable state) is on 11.

    The encoder position is stored in `self._value` and is accessed with `self.value()`. 

    The decoding is performed by the Pin interrupt handler `process_state()` which should be called when the state of
    either of the encoder pin changes.

    Principle of operation: each each time we call `process_state()`, we increment the `sub_incr` counter by the direction of
    movement (+1, -1) obtained from the previous and current encoder state. If the current encoder lands in its detent
    position ('11'), we add `sub_incr//4` to the counter, i.e. it will add +1 or -1 only if we have detected +4 or -4
    subincrements since the last detent landing.

    Invalid transition (skipping 2 encoder phases states) are problematic as we can't tell which direction we went. We
    try to salvage some of those those events and increase our accuracy by keeping track of these missed counts and
    adding later with the direction of the other valid increments. We don't use the missed counts if increment count is
    null. Of course this won't help if we miss too many states between `process_state()` calls.

    Parameters:

        pin_a, pin_b (machine.Pin): Pins connected to the rotary encoder.
            These pins must already have been configured properly.

        irq_wrapper (fn): If specified, wraps the Pin interrupt handler that tracks
            encoder movements. 

        verbose (int): verbose level for testing

    """

    # Direction table: maps the previous and current encoder pin values (Aprev Bprev Acur Bcur) to the direction of the
    # rotation. Values in parentheses indicate invalid changes (2 phase jumps = > ambiguous sign).
    dir_table = [
        0, -1, 1, (0), 1, 0, (0), -1,  # 0000, 0001, 0010, 0011, 0100, 0101, 0110, 0111
        -1, (0), 0, 1, (0), 1, -1, 0  # 1000, 1001, 1010, 1011, 1100, 1101, 1110, 1111
        ]
    def __init__(self, pin_a, pin_b, button_shift, irq_wrapper=None, verbose=2):
        self.pin_a = pin_a
        self.pin_b = pin_b
        self.button_shift = button_shift
        self._value = 0  # Continous count of valid increments/decrements without SHIFT 
        self._shift_value = 0  # Continous count of valid increments/decrements with SHIFT  
        self.prev_pins = 0b11  # stores the previous encoder pin state
        self.sub_incr = 0  # tracks cumulative phase increments between detents
        self.invalid = 0  # number of invalid state changes
        self.verbose = verbose

        # Set rotary encoder pins IRQ callback to the encoder handler so it can keep track of pin level changes. 
        # Use process_state() unless a custom handler is provided 

        irq_handler = irq_wrapper(self.process_state) if irq_wrapper else self.process_state;
        self.pin_a.irq(irq_handler) 
        self.pin_b.irq(irq_handler)
        # self.last_time = time.time()

    def value(self):
        return self._value

    def shift_value(self):
        return self._shift_value

    def reset(self):
        self._value = 0

    def process_state(self, pin):
        """ Encoder state processing method, meant to be used as an pin interrupt routine.

        Parameters:

            pin (machine.Pin): Pin that caused the interrupt, as passed by the pin interrupt handler to *both* encoder pins. This parameter is not used since we already know the two pins we need to probe.

        """
        pins = (self.pin_a.value() << 1) | self.pin_b.value() # get the two encoder pin values
        shift = self.button_shift.is_down()

        # Do nothing if the encoder pins have not changed. This happens often, 
        # so let's save some CPU cycles by stopping right here. 
        if pins == self.prev_pins: 
            return
        incr = self.dir_table[(self.prev_pins << 2) | pins] # get direction of rotation from previous and current state
        self.sub_incr += incr  # increment with direction between 
        self.invalid += not incr # count the number of invalid transition; we'll handle them later in the final detent tally
        if self.verbose:
            if self.verbose > 1:
                print(f'pins {self.prev_pins:02b}=>{pins:02b}, dir={self.dir_table[(self.prev_pins << 2) | pins]}, sub_incr={self.sub_incr}, invalid={self.invalid}')
            if not incr: 
                print(f'Missed a count!')
        self.prev_pins = pins
        old_counter = self._value  # debug
        if pins == 0b11: # we landed on the detent position. Assess our increment.
            # add sub_incr/4, after adding invalid counts as jumps of 2 in the direction of the valid ones
            incr = (self.sub_incr + (self.invalid << 1 if self.sub_incr > 0 else -self.invalid << 1 if self.sub_incr < 0 else 0)) >> 2
            self.sub_incr = self.invalid = 0 # start anew
            if shift:
                self._shift_value += incr
                self.button_shift.clear()
            else:
                self._value += incr
        if self.verbose and self._value != old_counter: 
            print(f'value={self._value}')
        # self.last_time = time.time()

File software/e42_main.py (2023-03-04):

from machine import Pin, SPI, SoftSPI
from e42_display import E42Display
from e42_button import E42Button
from e42_rotary import E42Rotary
from gui import GUI
import time
from umqttsimple import MQTTClient
import ubinascii
import machine
import micropython
import network
import esp
import json

config = None
spi = None
display = None
gui = None
client = None

client_id = ubinascii.hexlify(machine.unique_id())
topic_sub = b'notification'
topic_pub = b'home/sensor1/infojson'

last_message = 0
message_interval = 5
counter = 0


def sub_cb(topic, msg):
    print((topic, msg))
    if topic == b'notification' and msg == b'received':
        print('ESP received hello message')


def connect_and_subscribe():
    client = MQTTClient(
        client_id, config['mqtt_server'], user=config['mqtt_user'], password=config['mqtt_password'])
    client.set_callback(sub_cb)
    client.connect()
    client.subscribe(topic_sub)
    print('Connected to %s MQTT broker, subscribed to %s topic' %
          (config['mqtt_server'], topic_sub))
    return client


def restart_and_reconnect():
    print('Failed to connect to MQTT broker. Reconnecting...')
    time.sleep(10)
    machine.reset()


def load_config():
    global config
    try:
        with open('config.json') as json_file:
            config = json.load(json_file)
    except:
        return False
    return True


def init():
    pin_sck = Pin(6, Pin.OUT)
    pin_mosi = Pin(7, Pin.OUT)
    pin_miso = Pin(2, Pin.IN)
    pin_cs = Pin(20, Pin.OUT)
    pin_cd = Pin(1, Pin.OUT)
    pin_res = Pin(0, Pin.OUT)

    global spi
    spi = SPI(1, baudrate=5000000, sck=pin_sck, mosi=pin_mosi, miso=pin_miso)
    global display
    display = E42Display(spi=spi, cs=pin_cs, cd=pin_cd, res=pin_res)


def dispose():
    display.clear()
    global spi
    spi.deinit()
    spi = None


def start_gui():

    global counter
    counter = 0

    rot_enc = E42Rotary(pin_num_clk=9, pin_num_dt=10, pull_up=True)
    button_rot = E42Button(Pin(8, Pin.IN, Pin.PULL_UP), None)
    button_a = E42Button(Pin(5, Pin.IN, Pin.PULL_UP), None)
    button_b = E42Button(Pin(4, Pin.IN, Pin.PULL_UP), None)
    button_c = E42Button(Pin(3, Pin.IN, Pin.PULL_UP), None)

    display.clear()

    global gui
    gui = GUI(display, rot_enc, button_rot, button_a, button_b, button_c)

    gui.draw_text(0, 0, "EEMON42", 255, 255, 0)


def start_client():

    if not load_config():
        print("Unable to load the configuration")
        return

    station = network.WLAN(network.STA_IF)

    if station.isconnected():
        station.disconnect()

    station.active(True)
    station.connect(config['ssid'], config['password'])

    while station.isconnected() == False:
        pass

    print('Connection successful')
    print(station.ifconfig())

    global client
    try:
        client = connect_and_subscribe()
    except OSError as e:
        restart_and_reconnect()


def main_loop():

    global last_message, counter

    while True:
        try:
            counter += 1
            if client:
                client.check_msg()
                if (time.time() - last_message) > message_interval:
                    msg = json.dumps({"counter": counter})
                    client.publish(topic_pub, msg)
                    last_message = time.time()
        except OSError as e:
            restart_and_reconnect()


def run():
    init()
    start_gui()
    # start_client()
    print(gui.show_text_input(0, 1, 8))
    try:
        main_loop()
    except KeyboardInterrupt:
        print('Interrupted')
        dispose()

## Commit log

2022-09-03 First commit if the schematics and pcb
    [ADE7816.kicad_sch, emon36.kicad_pcb, emon36.kicad_sch]
2022-09-03 Added 3D models in LFS
    [ADE7816ACPZ.stp, CUI_DEVICES_MJ-3523-SMT-TR.step, Cap_Murata_GRM188C71C225KE11D_eec.STEP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]
2022-09-04 Added symbol and 3d_model for Digilent PModOLED, and symbol only for PmodOledrgb
    [PmodOLED.STP]
2022-09-05 Added Digilent PmodOLEDrgb footprint with rough 3d model
    [PmodOLEDrgb.STEP]
2022-09-10 Add preliminary USB interface
    [629105150521 (rev1).stp, ADE7816.kicad_sch, emon36.kicad_pcb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]
2022-09-10 Add tactile switch footprint and 3d model
    [PTS645SK13SMTR92LFS.stp]
2022-09-11 Reverted to stacked 3.5mm connectors. Now has 42 channels. Added OLED, switches, power system. Cleaned up channel page.
    [0.96in Color OLED.stp, ADE7816.kicad_sch, PmodOLED.STP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]
2022-09-11 schematics: Added todo list, 2nd AC connector, series caps to SPI terminations.
    [emon36.kicad_sch]
2022-10-14 Another major schematics/PCB iteration. Added decoupling caps, interrupts, etc. Improved power system. Added clock.
    [ADE7816.kicad_sch, emon36.kicad_pcb, emon36.kicad_sch]
2022-12-03 Finished schematics, layout and routing. Ready for verification.
    [ADE7816.kicad_sch, EEUFR1V681L.step, PJ-002A.step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]
2022-12-05 Added lots of silkscreen info. Added silk clearance and JLCPCB stackup. Improved Dc-DC with copper pours. Added SPI testpoints.
    [10118194-0001LF.step, ADE7816.kicad_sch, Bourns_SRN8040TA_series_H3_7mm.step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]
2022-12-06 Schematics: completed/updated some part number fields. Changed 4.7uF to 16V for better effective capacitance. Cleanup top sheet.
    [ADE7816.kicad_sch, emon36.kicad_sch]
2022-12-08 Added IRQ diodes - ADE7816 IRQs not open collector. Added pin 1 markers. Increased track widths. Cleanup. Made OLED mounting holes non plated.
    [ADE7816.kicad_sch, emon36.kicad_sch]
2022-12-09 Added an optional pullup resistor in case the internal one is not strong enough to boas all the IRQ diodes.
    [ADE7816.kicad_sch, emon36.kicad_sch]
2022-12-16 Added diodes on IRQ, included solder mask and silk constraints, fix silk. Version sent to production.
    [ADE7816.kicad_sch, emon36.csv, emon36.kicad_sch]
2022-12-16 Added production gerber (LFS)
2022-12-16 Renamed files to EEMON42
    [eemon42.csv, eemon42.kicad_sch]
2022-12-16 Renamed emon36 folder to eemon42
    [0.96in Color OLED.stp, 10118194-0001LF.step, 629105150521 (rev1).stp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]
2023-01-26 Fix OLED not drawing properly
    [ssd1331.py]
2023-01-26 Add rotary encoder handling
2023-03-04 Added e2_spi.py with SPI_with_CS class to handle dual-function CS pins. Adapted ade7816 to micropython and new SPI interface.
2023-03-05 Added home-made rotary switch handler. Updated test() method
2023-03-06 e42_rotary2.py: re-thought the rotary encoder decoding algorithm, which is now more robust. Tweaked the SPI_with_CS API, using preallocated buffers for speed. Use buffers for ADE7816 read/write_reg (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
2023-03-14 Simulation code in separate directory and integration of new rotary encoder
2023-03-27 sim: button: Modified so it can be used by main code directly. Added method to set rectangle.
2023-03-27 spi: renamed e42_spi to spi. dual-use pins are now passed as a list, not a dict. All methods should pass the CS pin object, not device name. Updated irq wrapper: now only wraps, does not set IRQ. Add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
2023-03-27 ade7816: support new spi API.
2023-03-27 rotary_encoder: renamed from e42_rotary2. Now sets pin IRQ, with optional wrapper function.
2023-03-27 ssd1331: renamed from display.py. Supports new spi API.
2023-03-27 gui: Implement menu system as coroutine. Moved test_input() menu as a gui method (becomes shorter and more efficient).
    [gui.py]
2023-03-27 eemon42.py: renamed from main.py. Refactor using classes and asyncio. Wifi & MQTT are now background processes running concurrently with the gui coroutine. Handled cancellation and keyboard interrupt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
2023-03-27 sim: main: refactored simulator to use coroutines and new factored code. Simplify some code. Completely uses the original micropython code. Added library overrides and display/button post-init config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
2023-03-27 umqttsimple: attempt to make it compatible with Cpython. Currently have errors when trying to connect to Mosquitto
    [umqttsimple.py]
2023-03-29 spi: added a SPI.deinit() before creating a new SPI object, otherwise the port does not work.
    [spi.py]
2023-03-29 Moved display init from gui.run() to eemon42.__init__() so we know if the board is alive.
2023-03-29 button: Added IRQ wrapper for the button. Used a irq to detect when button is pressed. button is not functional: need new code to debounce and properly increment _value.
2023-03-30 boot: start eemon42 application if we hold button C at boot.
2023-03-30 button: implemented IRQ-baes basic debouncing. not perfect. Removed unused code.
2023-03-31 button: implement a better debouncing algorithm that does not require a Timer.
2023-04-02 Cleanup button code
2023-04-02 Add frame buffer and optimize display
2024-09-23 feat (ssd1331): cleanup, move higher-level frame buffer functions to display module.
2024-09-23 feat (display): added generic framebuffer/display module. Moved in print functions. Added 5x7 font.
2024-09-23 feat (ade7816): better handling of reg data formats. Implement init(), interrpt handling, current/voltage/energy calib. energy accumulation. Uses linecycle energy readout mode..
2024-09-23 fix (sims): updated simulated device code to match latest architecture
    [ade7816.py, main.py, rotary_encoder.py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]
2024-10-08 feat (gui): Normalize button functions, simplify and add shift-rorate to edit_box, added list_box.
2024-10-08 feat (eemon42): Added pin interrupt on IRQ with ThreadSafeflag, added screen saver, improve emon readout loop.
2026-09-27 fix (button): add debug info
    [button.py]
2026-09-27 fix (ADE7816): Updated registers of energy monitor chip, added config struct , added measurement params
    [ade7816.py]
2026-09-27 fix (SSD1331): Receive framebuffer, use new Display.
    [ssd1331.py]
2026-09-27 sim (button, ade7817):: improve simulated modules
2026-09-27 fix (eemon42): Support multiple displays. Pre-allocate frame buffer to minimize fragmentation. use sim shadow modules. use menus. Network connection is now an event. Added home assistant publishing. 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
    [eemon42.py]
2026-09-27 fix (display, font): Generalize display. Added fonts.
    [display.py, font.py]
2026-09-27 fix (gui): Cleanup GUI objects
    [gui.py]
2026-09-27 fix (display, encoder): updated pygame display and encoder objects.
    [rotary_encoder.py]
2026-09-27 fix (main): cleanup main, and setup python path for sims
    [main.py]
2026-09-27 fix: removed unused files
    [hass.py]
2026-09-27 fix (hass, gitignore): Moved hass ip/port to secrets. Excluded some kicad files from git.
    [hass.py]
2026-10-04 fix (all): Many fixes:
    - create pyproject.toml for uv.
    -Restructure folders into embed/ and sim/.
    - Have sim module shadow embed ones when on a pc.
    - FIx display management.
    - Cleanup and integrate home assistant code.
    - Fix menu erase on exit.
    - Load network at beginning to handle fragmentation.
    [ade7816.py, boot.py, button.py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]
